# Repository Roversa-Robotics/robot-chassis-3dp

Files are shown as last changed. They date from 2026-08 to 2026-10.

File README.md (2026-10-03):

# robot-chassis-3dp

A 3D-printable (3DP) chassis for the Roversa robot, designed in Fusion 360.

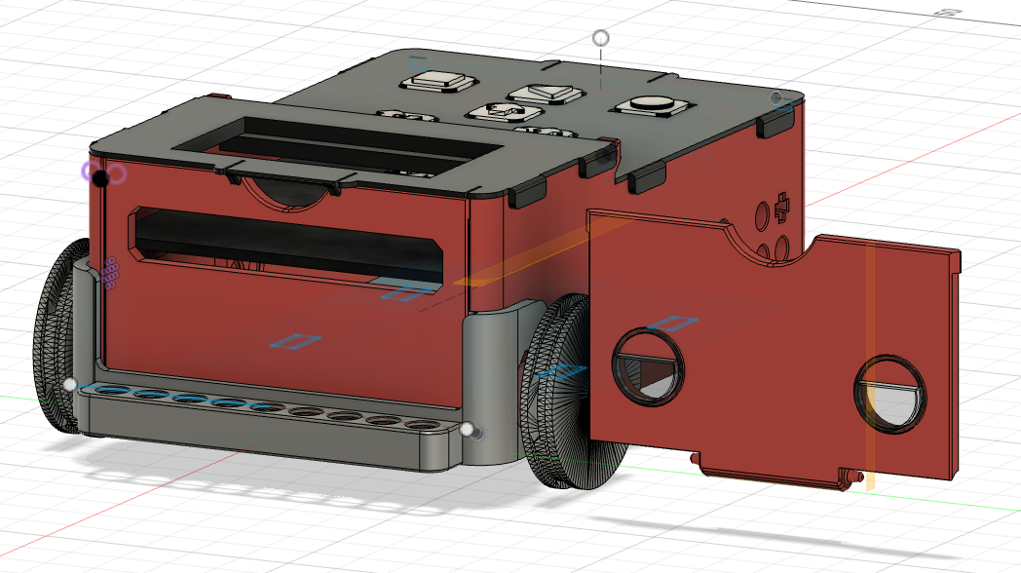
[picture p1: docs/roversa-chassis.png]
Roversa Chassis


Credit to the Paola Harris Bonet at Universidad del Norte for the initial design that I've built upon.

The design uses common parts also used in the Laser Cut (LC) version of the chassis--the buttons, wheels, and ball bearing holder (but not the battery holder from the LC version). The Roversa PCB board, servos, battery and Micro:Bit complete the assembly.

## Repository contents

```
charging-station-3dp/
├── LICENSE
├── README.md
├── cad/              Source Fusion 360 (.f3d) archives
└── exports/
    ├── stl/          Generated STL files, ready to slice/print
    └── step/         Generated STEP files, for use in other CAD tools
```

- **`cad/`** — Archived versions of the Fusion 360 source file. Since `.f3d`
  is a binary format, version history here is file-based rather than
  diff-based — see [Versioning](#versioning) below.
- **`exports/stl/`** and **`exports/step/`** — Generated output files. These need to 
  be regenerated any time the `cad/` version is updated and should be committed in the
  same pull request with the `.f3d` update. 
  
Although this design includes buttons and wheels for a complete assembly, they are maintained in the LC Chassis design in OnShape. Only the following STL files come from this design:
- roversa-body.stl (from the CUERPO body)
- roversa-front.stl (from the PUERTA PRINCIPAL body)
- roversa-back.stl (from the PUERTA TRASERA body)
- roversa-microbit-cover.stl (from the TAPA MICROBIT body)
- roversa-buttons-cover.stl (from the TAPA BOTONES body)
- roversa-battery-cover.stl (from the TAPA BATERIA body)
- roversa-motor-tension-block.stl (from the SERVO TENSOR body)

Additionally, the following 'extra' files are exported from the design for optional components:
- extras/bumper/roversa-bumper.stl (from the BUMPER body)
- extras/bumper/pen-clamp-body.stl (from the pen-clamp fusion project)
- extras/bumper/pen-clamp-screw.stl (from the pen-clamp fusion project)
- extras/license-plate/roversa-license-plate.stl (from the PLACA body)
- extras/front-with-eyes/roversa-front-with-eyes.stl (from the PUERTA CON OJOS body)
- extras/front-with-eyes/roversa-eye.stl (from the OJOS 1 body)
- extras/flag/base-with-flag.stl (from the roversa_flag fusion project)

Finally, the following files were created in other modeling tools but a copy is maintained in this project because they are necessary for assembling the robot:
- externals/Back_button.stl - mastered in OnShape
- externals/Forward_button.stl - mastered in OnShape
- externals/Left_button.stl - mastered in OnShape
- externals/Menu_button.stl - mastered in OnShape
- externals/Play_button.stl - mastered in OnShape
- externals/Right_button.stl - mastered in OnShape
- externals/Stop_button.stl - mastered in OnShape
- externals/roversa_battery_holder_v3.stl - only used for lasercut robot
- externals/roversa_bearing_support_split_v3.stl - master not available
- externals/roversa_wheel_F_v3.stl - master not available
- externals/roversa_wheel_M_v3.stl - master not available

## Software

- **Fusion 360** — primary CAD tool used for design.

## Printing notes

The parts have been test printed using PETG with a Bambu X1C with `0.16mm Optimal @BBL X1C` settings on the Textured PEI plate.

## Versions

Versions are numbered using semantic versioning (major.minor.patch numbering). Each update that is committed to source control should have a corresponding version number update in Fusion 360.

## License

This project is licensed under the [MIT License](LICENSE).

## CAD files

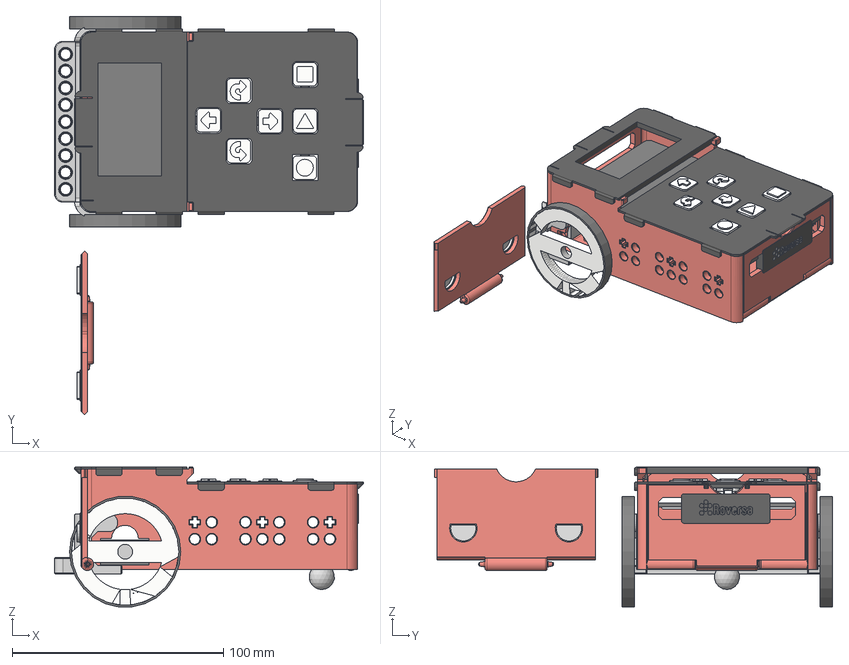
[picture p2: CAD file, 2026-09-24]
cad/roversa-robot-chassis-3dp.step
146.4 x 188.5 x 66.2 mm

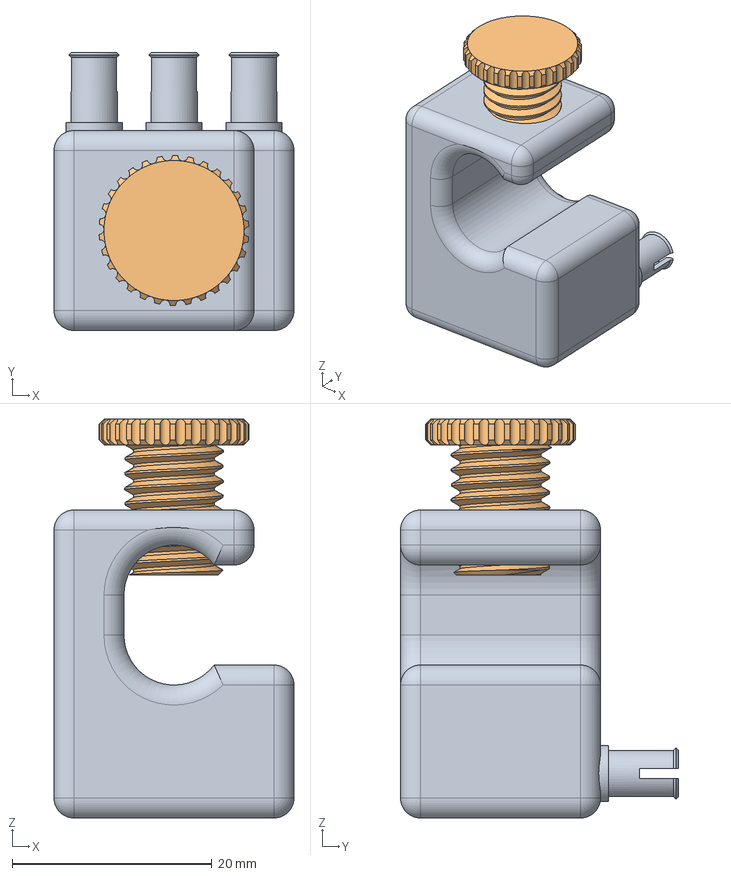
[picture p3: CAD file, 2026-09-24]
exports/step/pen-clamp.step
24.0 x 27.8 x 39.9 mm

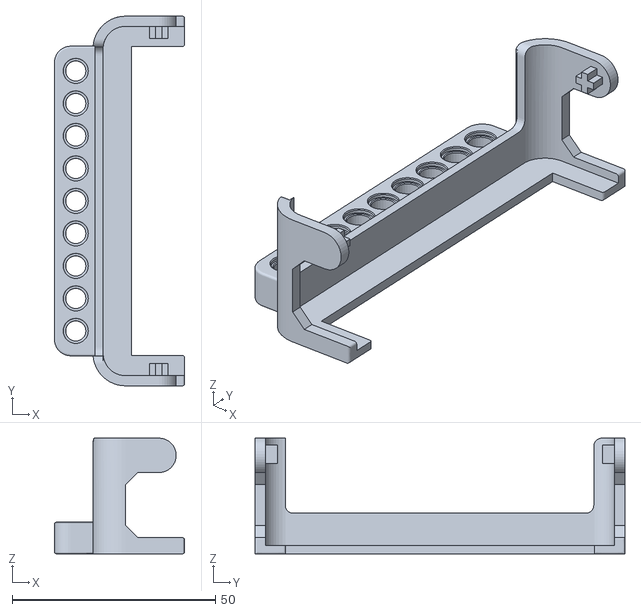
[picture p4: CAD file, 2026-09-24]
exports/stl/extras/bumper/roversa-bumper.stl
32.0 x 91.0 x 28.5

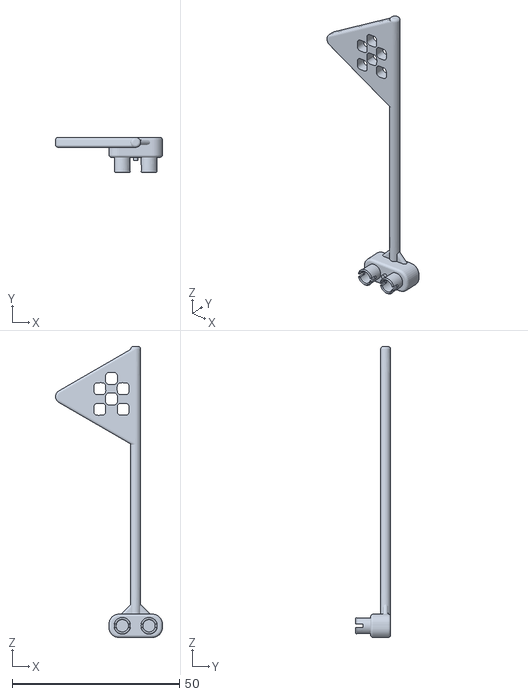
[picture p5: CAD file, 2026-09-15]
exports/stl/extras/flag/base-with-flag.stl
32.0 x 10.6 x 87.0

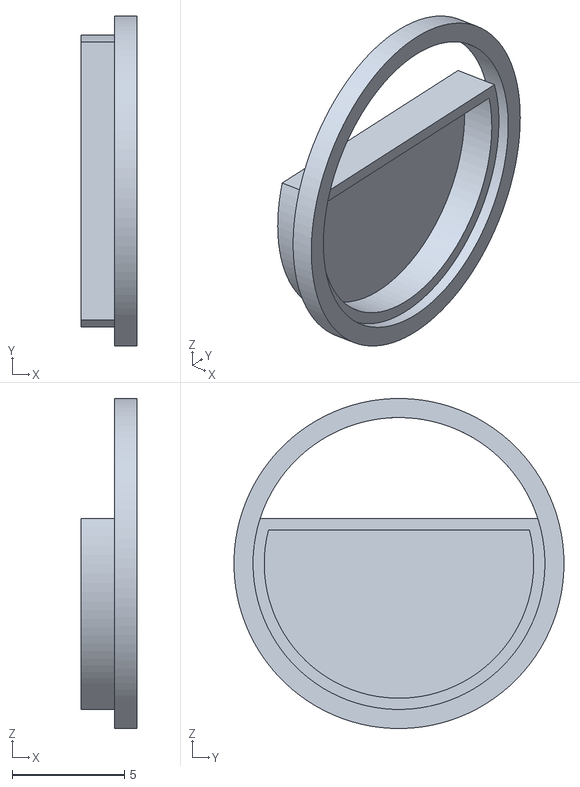
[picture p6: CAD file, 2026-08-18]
exports/stl/extras/front-with-eyes/roversa-eye.stl
2.51 x 14.7 x 14.7

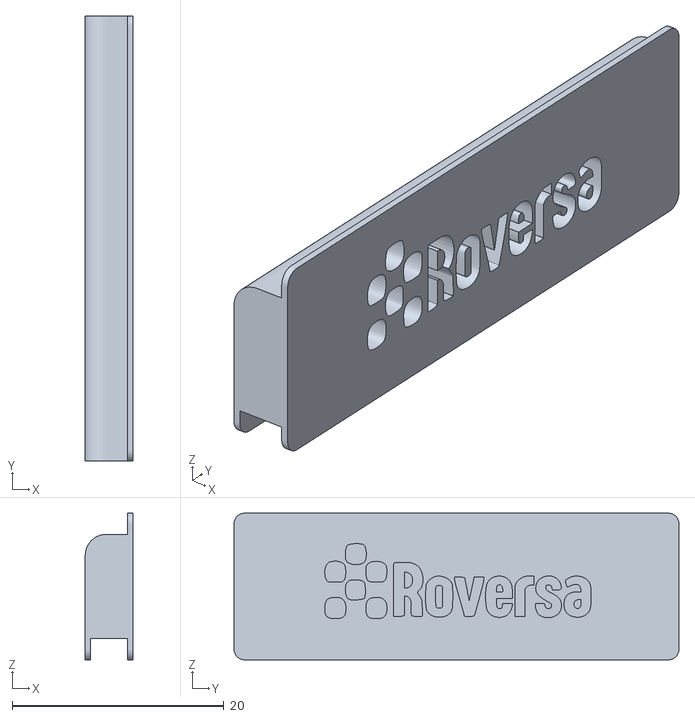
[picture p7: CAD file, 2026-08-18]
exports/stl/extras/license-plate/roversa-license-plate.stl
4.50 x 42.0 x 13.9

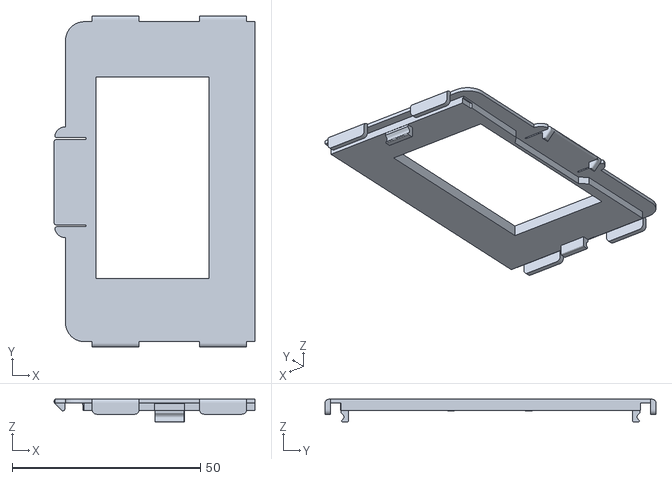
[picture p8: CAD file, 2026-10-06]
exports/stl/roversa-microbit-cover.stl
53.2 x 87.8 x 6.00

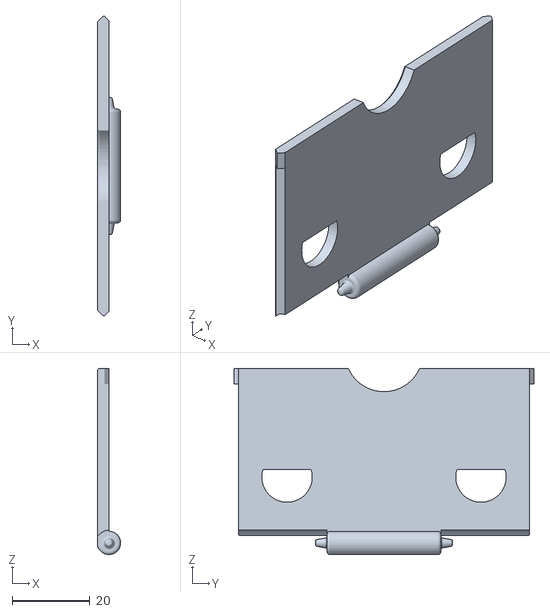
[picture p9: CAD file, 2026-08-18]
exports/stl/extras/front-with-eyes/roversa-front-with-eyes.stl
6.00 x 77.4 x 48.0

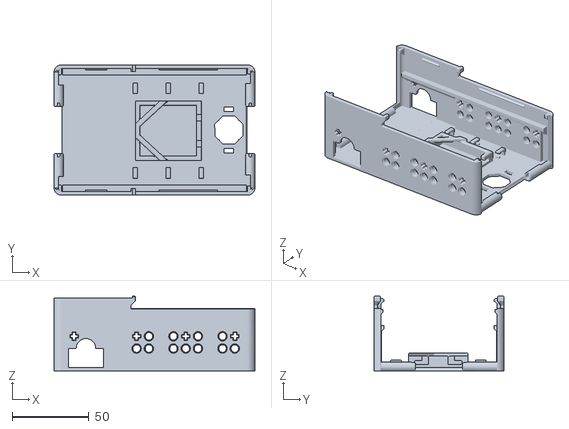
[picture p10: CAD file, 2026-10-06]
exports/stl/roversa-body.stl
131.1 x 85.0 x 48.6

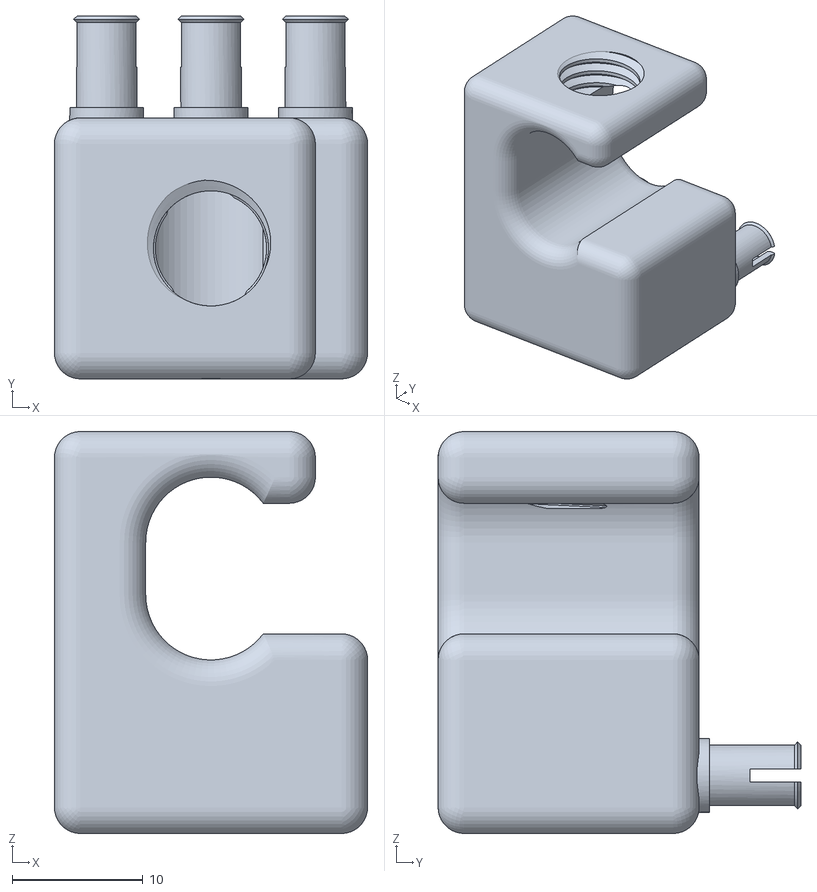
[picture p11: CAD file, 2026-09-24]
exports/stl/extras/bumper/pen-clamp-body.stl
24.0 x 27.8 x 30.8

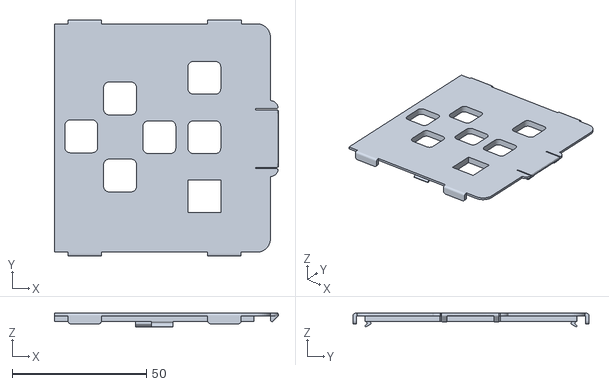
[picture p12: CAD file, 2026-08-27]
exports/stl/roversa-buttons-cover.stl
83.3 x 88.0 x 5.07

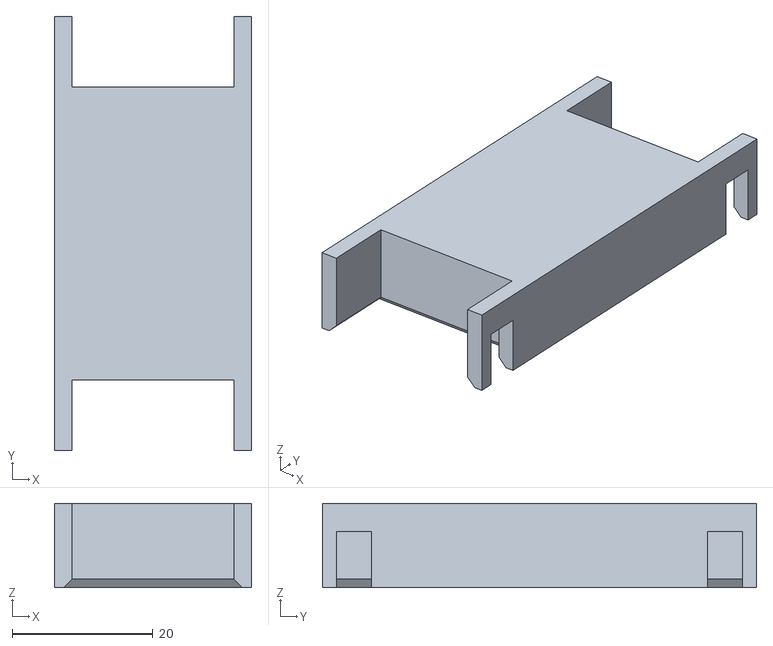
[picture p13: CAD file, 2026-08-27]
exports/stl/roversa-motor-tension-block.stl
28.0 x 61.7 x 12.0

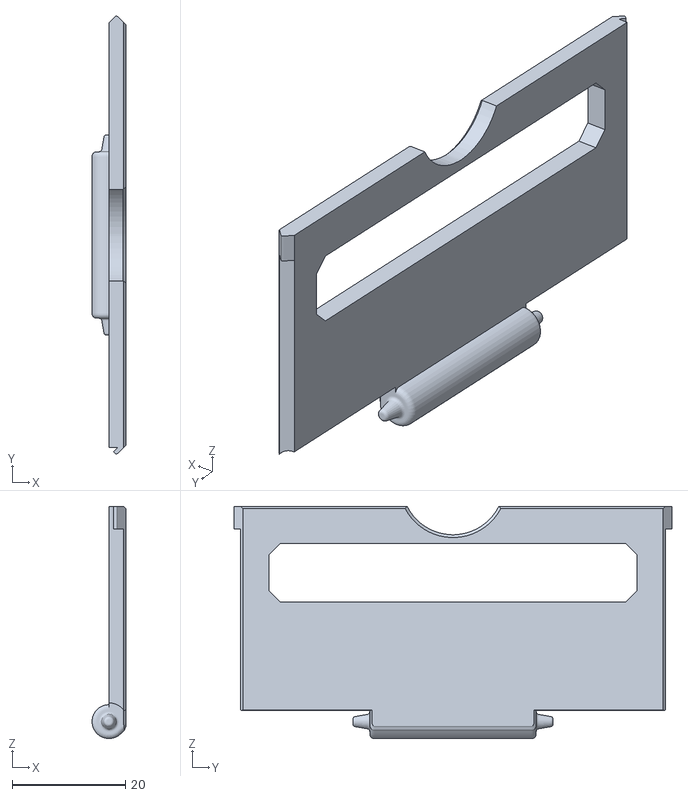
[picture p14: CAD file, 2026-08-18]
exports/stl/roversa-back.stl
5.99 x 77.4 x 41.0

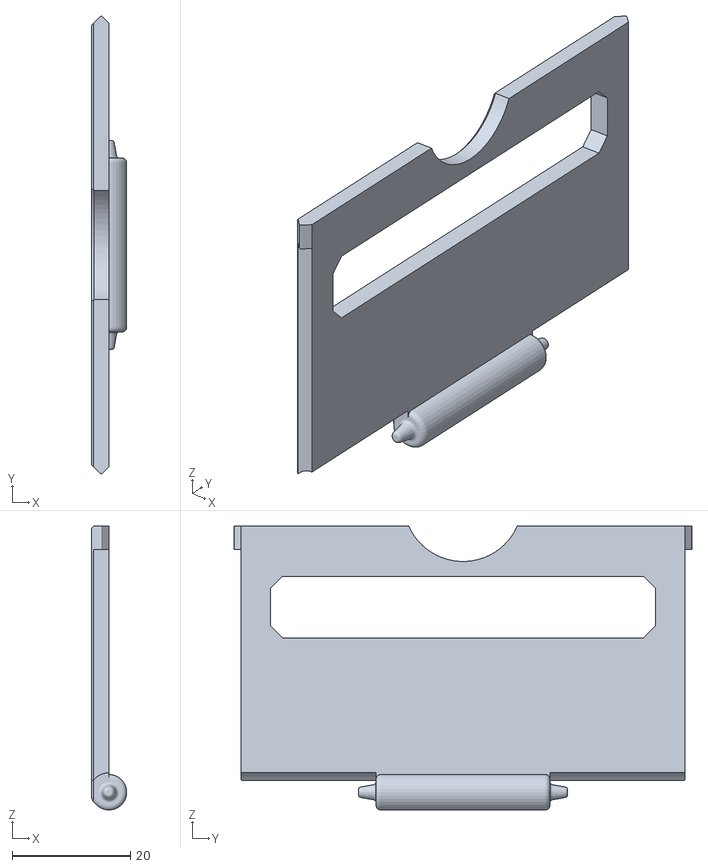
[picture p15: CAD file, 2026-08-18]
exports/stl/roversa-front.stl
6.00 x 77.4 x 48.0

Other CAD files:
exports/step/roversa_flag.step
exports/stl/extras/bumper/pen-clamp-screw.stl
cad/pen-clamp.f3d
cad/roversa-robot-chassis-3dp.f3d
cad/roversa_flag.f3d
exports/step/roversa-robot-chassis-3dp.step

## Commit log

2026-08-14 initial fusion archive
    This was the first Fusion 360 archive of the robot
    chassis that Paola shared with me. I am seeding the
    github history with this as the initial version
2026-08-14 replace ribs with motor tension block
    This was the '3b' version of the design that I shared
    with Paola.
    It adds a 'motor tension block' (a new body called TENSOR SERVO) and
    updates the CUERPO design to remove the ribs that were intended to
    hold the servos in place. It is intended to keep the motors
    (and therefore wheels) from wobbling.
2026-08-14 This was the '3c' version of the design that I shared with Paola.
    It adds updates the battery cover to incorporate a block on the
    back side and a cantilever latch on the front end to hold it
    more firmly in place since it was previously prone to sliding
    off and rattling around in side the robot.
    No STL or STEP files for these historical versions. I'll generate those once we're up to the current version.
2026-08-14 3d update - front window + other tweaks
    This is the '3d' update I shared with Paola. It
    includes several small changes...
    On the CUERPO 1 body:
    - I removed the ribs from the rectangle slots where the
    ball bearing holder attaches.
    - I added a small chamfer where the front door hinge attaches
    to make it easier to connect the front door to the main body.
    - I replaced RUEDA LOCA with a mesh for the updated design
    from Cyril--his 'roversa_bearing_support_split_v3' version.
    On the PUERTA body (hinged front door - renamed from Body47 or something like that):
    - I added a rectangle window with chamfered corners to make the
    micro:bit USB port accessible. It matches the window on the back,
    minus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
2026-08-14 stl & step exports
    [roversa-battery-cover.stl, roversa-body.stl, roversa-buttons-cover.stl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]
2026-08-15 List generated STL files in readme
2026-08-16 version 3.5
    - switching to numbered versions instead of '3e'
    (previous version was 3d)
    - add curved cutout above servo holes to avoid 3d printing supports
    - replace back wall with hinged door to avoid 3d printing supports
    - also makes it easier to access interior components
    - add wedge latches for holding front and back doors closed
    - also allows opening the doors without removing the top
    - rotate door hinge slot to top (12:00) for easier install of door
    [roversa-back.stl, roversa-body.stl, roversa-buttons-cover.stl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]
2026-08-18 v3.5.1 - connector sockets, bumper, better license plate
    Added sockets for snap-fit pins and cross axles on sides of body (CUERPO).
    Adjusted license plate (PLACA) for easier install/more reliable fit & removed notches from back door (PUERTA TRASERA). Adjusted front door to have the sme height window so plate can fit either front 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
    Created an initial bumper that hooks onto one of the new cross axle sockets on either the front or back. Further front and back features (like sensor attachments or a pen holder) can be built out fro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
    Added exports of extras.
    Cleaned up unused bodies and renamed a few for better clarity.
    [roversa-back.stl, roversa-body.stl, roversa-bumper.stl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]
2026-08-27 Version 3.5.2 - thicker walls for motor tension block;
    - made side walls of motor tension block thicker to avoid them breaking
    - I improved the attachment for microbit & button covers for easier assembly
    - rounded corners where bottom meets the door hinges at front and back
    [roversa-body.stl, roversa-buttons-cover.stl, roversa-microbit-cover.stl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]
2026-09-15 v3.5.2 - add flag
    adds the flag, linked from the roversa_flag
    fusion360 project
    [2x-cover-sets.3mf, base-with-flag.stl, body-front-back.3mf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]
2026-09-24 v3.5.3 - add connector sockets to bumper + create pen clamp attachment
    - add connector sockets to bumper
    - thicken bumper walls
    - create pen clamp attachment with pen-clamp & pen-clamp-screw
    [2x-cover-sets.3mf, pen-clamp-body.stl, pen-clamp-screw.stl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]
2026-10-03 Version 3.5.4 - import real wheels
    - added actual wheels from Cyril's STLs
    - converted imported meshes to regular bodies
    - included all STLs needed for complete robot assembly
    [roversa-robot-chassis-3dp.f3d]
2026-10-03 Version 3.5.5 - make battery cover easier to install
    [roversa-battery-cover.stl, roversa-body.stl, roversa-robot-chassis-3dp.f3d]
2026-10-06 Version 3.6.0 - eliminate battery cover + improved sockets & easier assembly
    - converted battery holder to use cross-bars and wire slot instead of separate cover
    - removed stray slot in microbit-cover
    - adjusted ribs for cover attachments + microbit-cover clip for easier attachment
    - renamed bodies to have english names that match the exports (Lo siento, Paola)
    - grouped bodies according to how they are exported
    - changed motor wire stays to 'C' shape so they'll hold the wires better
    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
    [body-front-back.3mf, cover-set.3mf, roversa-battery-cover.stl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]
2026-11-08 add specs for lego-compatible sockets/posts
